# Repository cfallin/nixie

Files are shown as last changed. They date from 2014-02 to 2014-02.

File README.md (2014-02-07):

These are the raw Eagle schematic/PCB design files and the AVR firmware for a
Nixie tube clock.

Nixie tubes are gas-discharge neon display tubes. They take ~150 volts at a few
milliamps and glow a soft, pleasing orange. Each digit is a separate cathode in
a particular shape, so the numerals look more natural than more contemprary
7-segment display designs.

This project is a small microcontroller-based digital clock using 6 nixie tubes
(for HH:MM:SS). An ATmega16 8-bit AVR microcontroller keeps time based on its
20MHz system clock provided by a crystal oscillator, and controls six digit
driver ICs, one per Nixie tube. Each driver has high-voltage open-collector
outputs capable of directly interfacing with the display tube cathodes. The 150
volt anode supply is provided by a small switched-inductor boost converter,
which uses a power MOSFET driven by the microcontroller's PWM generator. The
design includes a feedback loop to an analog-to-digital (ADC) input on the AVR
so that it can regulate the tube voltage precisely.

Nixies can be found in various places online and often come from Russia. I
found mine on Etsy. Prices vary but I think the retro glow is well worth the
cost :-) The 74141 Nixie driver chips are also somewhat rare (e.g., not stocked
by Digikey) but can be found on eBay or at other small shops online.

=== DEVELOPMENT ENVIRONMENT ===

The firmware is written in C to be cross-compiled by avr-gcc. It assumes the
standard AVR headers that come with that compiler. The Makefile includes a
target to program the flash and fuses on the AVR using avrdude, but other
programmers can also be used.

The schematic and board were drawn in Eagle CAD. The additional libraries used
are included here.

=== IN PROGRESS ===

Work is currently in progress; in particular, the firmware is specific to an
earlier (hand-built) prototype version of the hardware and DOES NOT MATCH the
board. The board is currently (Feb 2014) out for a prototype run; when I build
the hardware designed here I'll update the firmware as appropriate.

=== LICENSE ===

All code, schematics and board design files here are Copyright (c) 2014 Chris
Fallin <cfallin@c1f.net>. Provided under the GNU GPL v2.

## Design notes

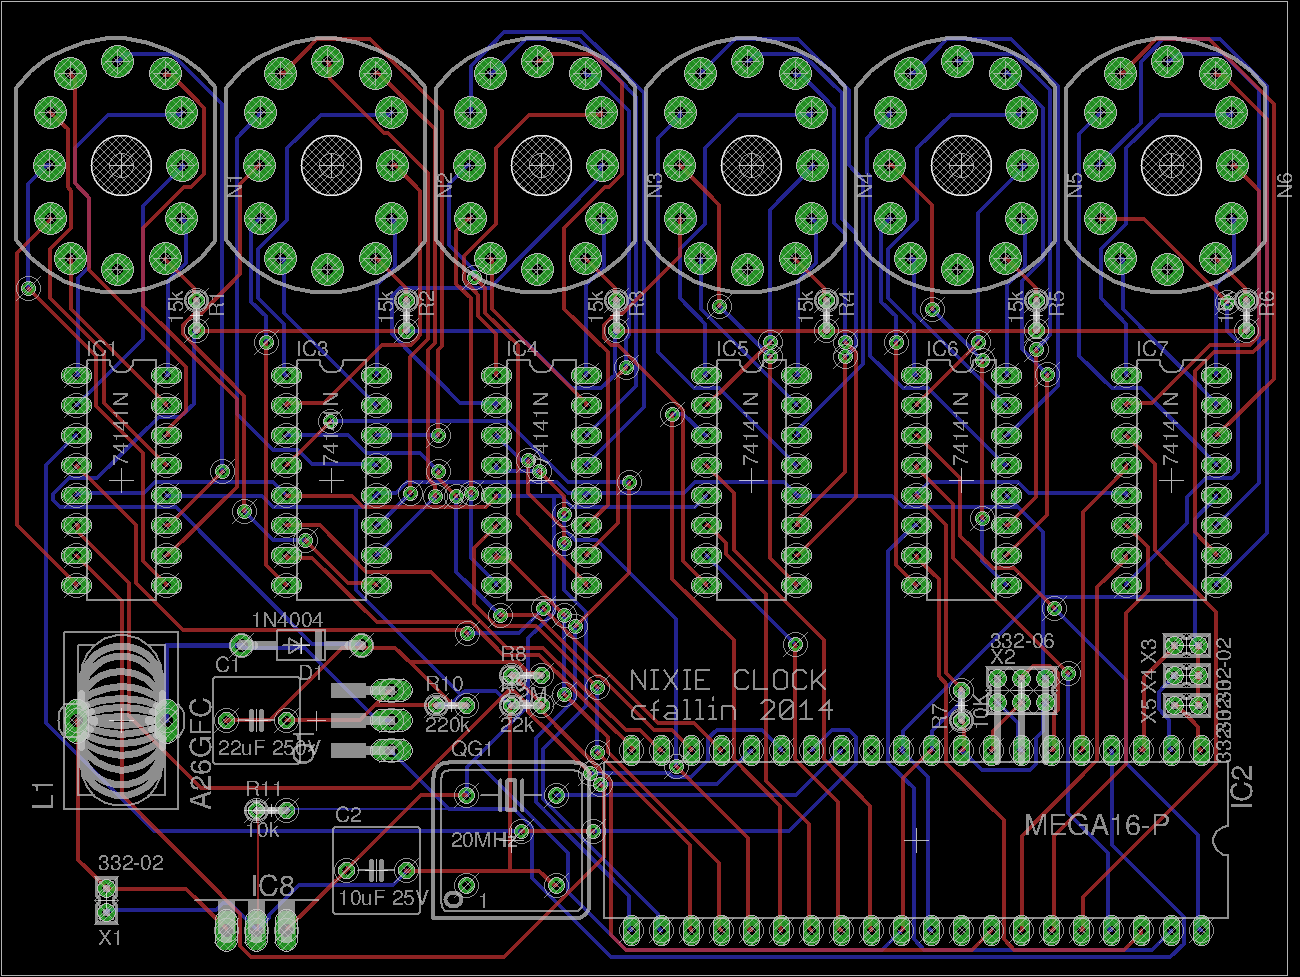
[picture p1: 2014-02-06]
board/nixie2.png

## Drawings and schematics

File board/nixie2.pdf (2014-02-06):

✁✂✁✂✄

☎✆

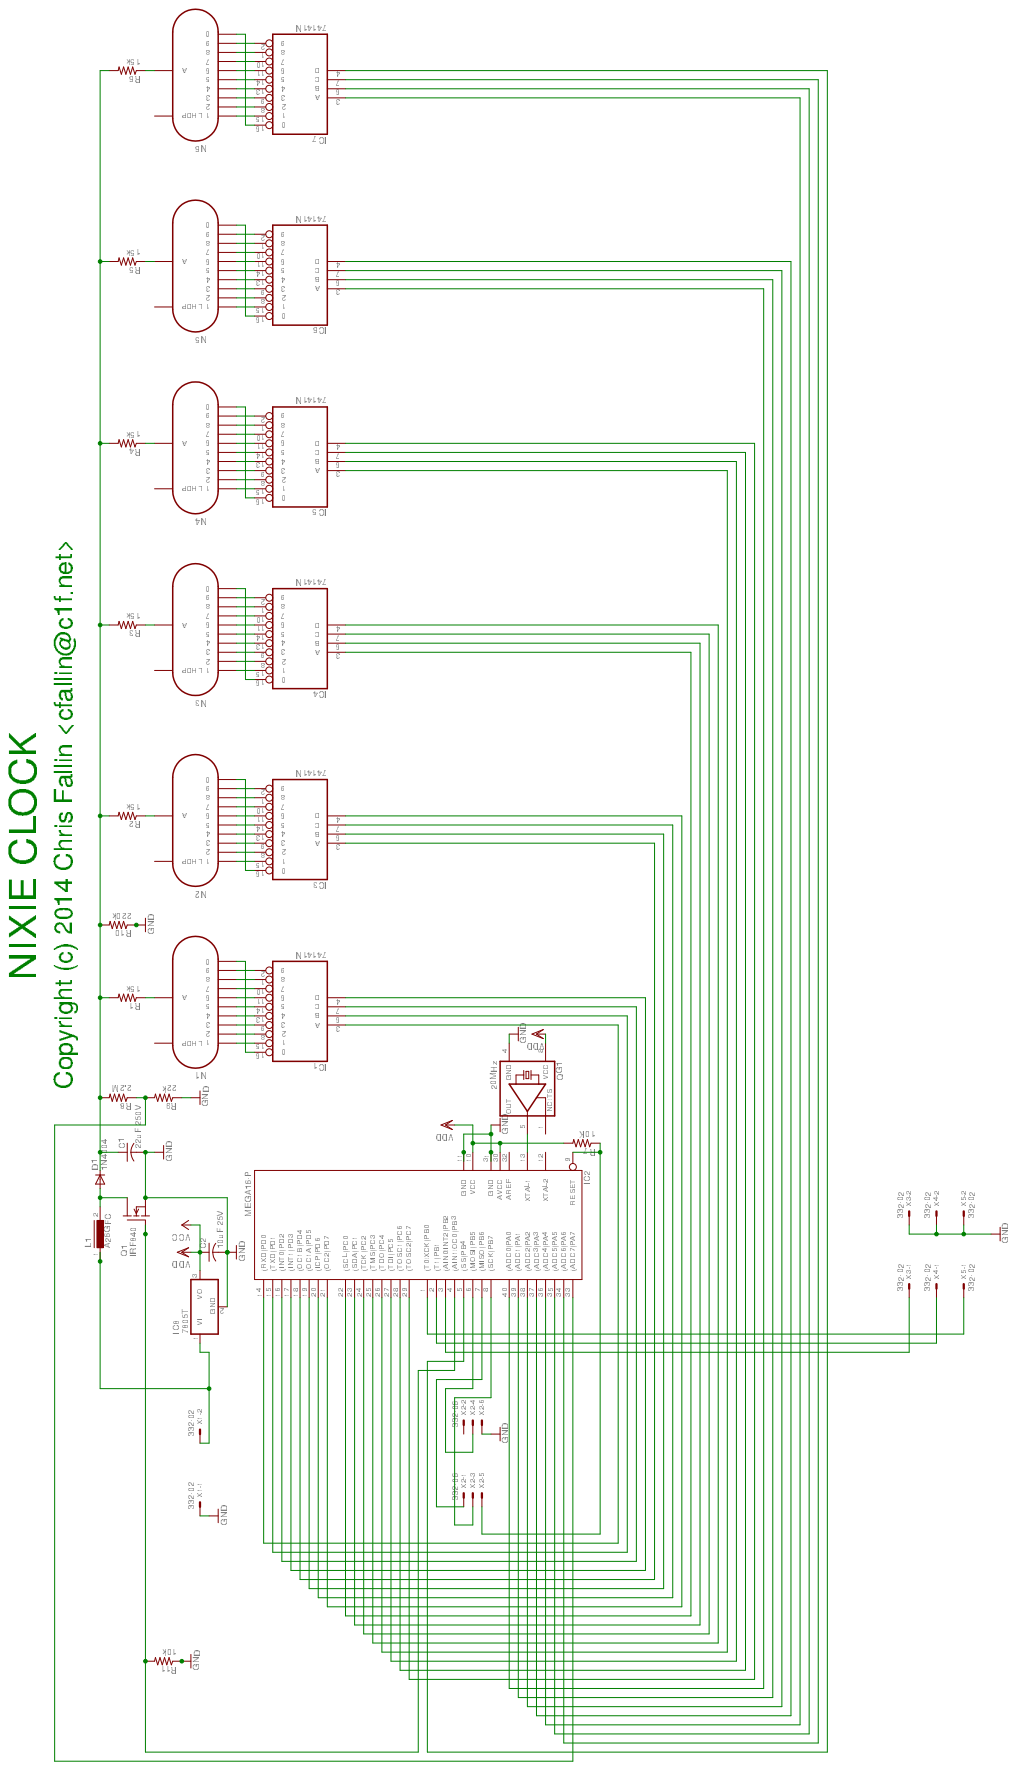
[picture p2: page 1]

✯✺
✯✯ | ✵
✯✵ | ✹
✯✳ | ✷

❦❧♠♥♦♣qrst✉✈✇①②③❦r♦♣④⑤⑥⑦⑦♣⑧⑨✉⑩⑥⑦⑦♣⑧❶✉②⑩❷⑧❸s❹

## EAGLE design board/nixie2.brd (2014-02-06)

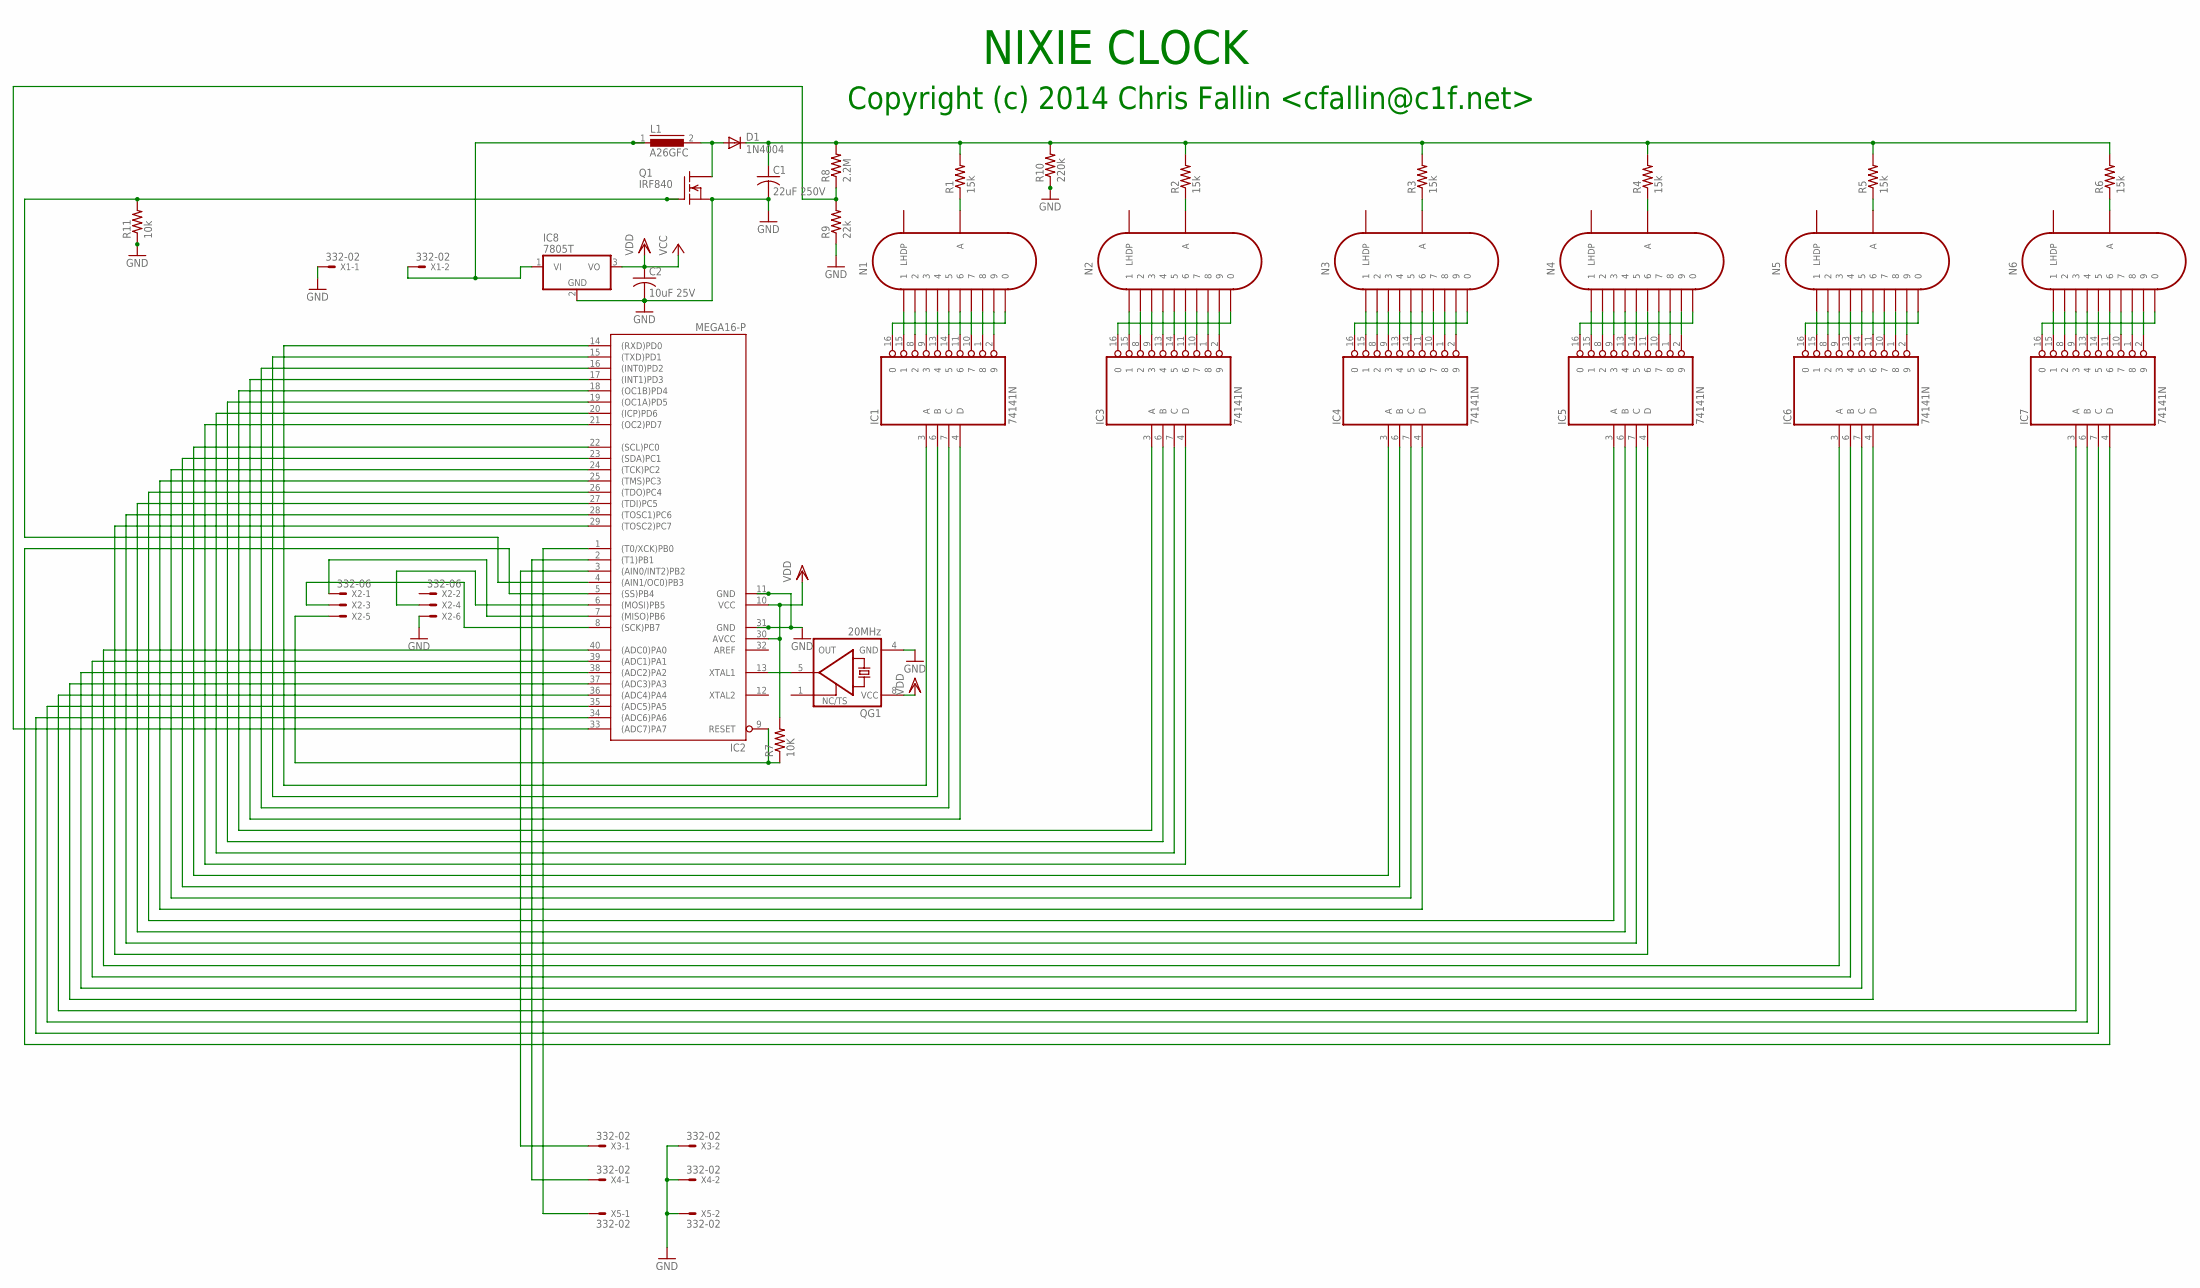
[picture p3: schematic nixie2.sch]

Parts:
C1: 22uF 250V; C050-075X075
C2: 10uF 25V; C050-075X075
D1: 1N4004; DO41-10
IC1, IC3, IC4, IC5, IC6, IC7: 74141N; DIL16
IC2: MEGA16-P; DIL40
IC8: 7805T; TO220H
L1: A26GFC
N1, N2, N3, N4, N5, N6: IN-12B; IN-12
Q1: IRF840; TO220
QG1: 20MHz; DIL08S
R1, R2, R3, R4, R5, R6: 15k; 0204V
R7: 10K; 0204V
R8: 2.2M; 0204V
R9: 22k; 0204V
R10: 220k; 0204V
R11: 10k; 0204V
X1, X3, X4, X5: 332-02
X2: 332-06

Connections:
GND: C1.2, C2.2, IC1.12 (GND), IC2.11 (GND), IC2.31 (GND), IC3.12 (GND), IC4.12 (GND), IC5.12 (GND), IC6.12 (GND), IC7.12 (GND), IC8.2 (GND), Q1.3 (S), QG1.4 (GND), R9.1, R10.1, R11.1, X1.1, X2.6, X3.2, X4.2, X5.2
unnamed: IC1.15 (1), N1.1
unnamed: IC1.8 (2), N1.2
unnamed: IC1.9 (3), N1.3
unnamed: IC1.13 (4), N1.4
unnamed: IC1.14 (5), N1.5
unnamed: IC1.11 (6), N1.6
unnamed: IC1.10 (7), N1.7
unnamed: IC1.1 (8), N1.8
unnamed: IC1.2 (9), N1.9
unnamed: N1.A, R1.1
unnamed: IC3.15 (1), N2.1
unnamed: IC3.8 (2), N2.2
unnamed: IC3.9 (3), N2.3
unnamed: IC3.13 (4), N2.4
unnamed: IC3.14 (5), N2.5
unnamed: IC3.11 (6), N2.6
unnamed: IC3.10 (7), N2.7
unnamed: IC3.1 (8), N2.8
unnamed: IC3.2 (9), N2.9
unnamed: IC3.16 (0), N2.0
unnamed: N2.A, R2.1
unnamed: IC4.15 (1), N3.1
unnamed: IC4.8 (2), N3.2
unnamed: IC4.9 (3), N3.3
unnamed: IC4.13 (4), N3.4
unnamed: IC4.14 (5), N3.5
unnamed: IC4.11 (6), N3.6
unnamed: IC4.10 (7), N3.7
unnamed: IC4.1 (8), N3.8
unnamed: IC4.2 (9), N3.9
unnamed: IC4.16 (0), N3.0
unnamed: N3.A, R3.1
unnamed: IC5.15 (1), N4.1
unnamed: IC5.8 (2), N4.2
unnamed: IC5.9 (3), N4.3
unnamed: IC5.13 (4), N4.4
unnamed: IC5.14 (5), N4.5
unnamed: IC5.11 (6), N4.6
unnamed: IC5.10 (7), N4.7
unnamed: IC5.1 (8), N4.8
unnamed: IC5.2 (9), N4.9
unnamed: IC5.16 (0), N4.0
unnamed: N4.A, R4.1
unnamed: IC6.15 (1), N5.1
unnamed: IC6.8 (2), N5.2
unnamed: IC6.9 (3), N5.3
unnamed: IC6.13 (4), N5.4
unnamed: IC6.14 (5), N5.5
unnamed: IC6.11 (6), N5.6
unnamed: IC6.10 (7), N5.7
unnamed: IC6.1 (8), N5.8
unnamed: IC6.2 (9), N5.9
unnamed: IC6.16 (0), N5.0
unnamed: N5.A, R5.1
unnamed: IC7.15 (1), N6.1
unnamed: IC7.8 (2), N6.2
unnamed: IC7.9 (3), N6.3
unnamed: IC7.13 (4), N6.4
unnamed: IC7.14 (5), N6.5
unnamed: IC7.11 (6), N6.6
unnamed: IC7.10 (7), N6.7
unnamed: IC7.1 (8), N6.8
unnamed: IC7.2 (9), N6.9
unnamed: IC7.16 (0), N6.0
unnamed: N6.A, R6.1
unnamed: C1.1, D1.C, R1.2, R2.2, R3.2, R4.2, R5.2, R6.2, R8.2, R10.2
unnamed: IC2.13 (XTAL1), QG1.5 (OUT)
unnamed: IC2.6 ((MOSI)PB5), X2.4
unnamed: D1.A, L1.2, Q1.2 (D)
unnamed: IC8.1 (VI), L1.1, X1.2
unnamed: IC2.7 ((MISO)PB6), X2.1
unnamed: IC2.8 ((SCK)PB7), X2.3
unnamed: IC2.9 (RESET), R7.1, X2.5
unnamed: IC1.3 (A), IC2.14 ((RXD)PD0)
unnamed: IC1.6 (B), IC2.15 ((TXD)PD1)
unnamed: IC1.7 (C), IC2.16 ((INT0)PD2)
unnamed: IC1.4 (D), IC2.17 ((INT1)PD3)
unnamed: IC2.18 ((OC1B)PD4), IC3.3 (A)
unnamed: IC2.19 ((OC1A)PD5), IC3.6 (B)
unnamed: IC2.20 ((ICP)PD6), IC3.7 (C)
unnamed: IC2.21 ((OC2)PD7), IC3.4 (D)
unnamed: IC2.22 ((SCL)PC0), IC4.3 (A)
unnamed: IC2.23 ((SDA)PC1), IC4.6 (B)
unnamed: IC2.24 ((TCK)PC2), IC4.7 (C)
unnamed: IC2.25 ((TMS)PC3), IC4.4 (D)
unnamed: IC2.26 ((TDO)PC4), IC5.3 (A)
unnamed: IC2.27 ((TDI)PC5), IC5.6 (B)
unnamed: IC2.28 ((TOSC1)PC6), IC5.7 (C)
unnamed: IC2.29 ((TOSC2)PC7), IC5.4 (D)
unnamed: IC2.4 ((AIN1/OC0)PB3), Q1.1 (G), R11.2
unnamed: IC2.40 ((ADC0)PA0), IC6.3 (A)
unnamed: IC2.39 ((ADC1)PA1), IC6.6 (B)
unnamed: IC2.38 ((ADC2)PA2), IC6.7 (C)
unnamed: IC2.37 ((ADC3)PA3), IC6.4 (D)
unnamed: IC2.36 ((ADC4)PA4), IC7.3 (A)
unnamed: IC2.35 ((ADC5)PA5), IC7.6 (B)
unnamed: IC2.34 ((ADC6)PA6), IC7.7 (C)
unnamed: IC2.5 ((SS)PB4), IC7.4 (D)
unnamed: IC2.33 ((ADC7)PA7), R8.1, R9.2
unnamed: IC2.3 ((AIN0/INT2)PB2), X3.1
unnamed: IC2.2 ((T1)PB1), X4.1
unnamed: IC2.1 ((T0/XCK)PB0), X5.1
unnamed: IC1.16 (0), N1.0
VDD: C2.1, IC1.5 (VCC), IC2.10 (VCC), IC2.30 (AVCC), IC3.5 (VCC), IC4.5 (VCC), IC5.5 (VCC), IC6.5 (VCC), IC7.5 (VCC), IC8.3 (VO), QG1.8 (VCC), R7.2

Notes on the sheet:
NIXIE CLOCK
Copyright (c) 2014 Chris Fallin <cfallin@c1f.net>

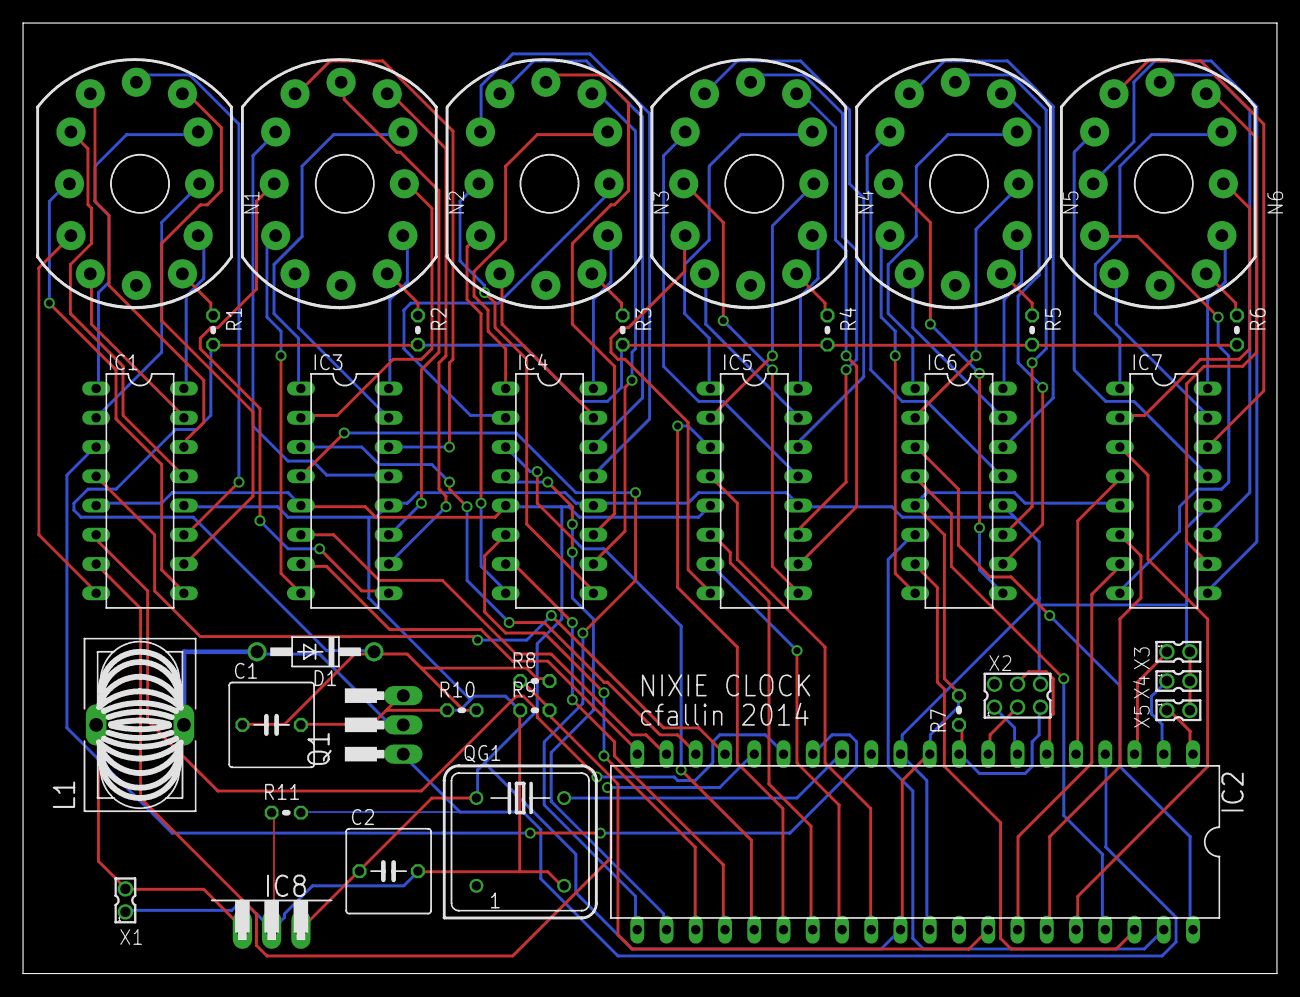
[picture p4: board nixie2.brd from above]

Board: 2 copper layers, 108.9 x 82.5 mm, 36 parts (0 on the bottom side), 105 nets.

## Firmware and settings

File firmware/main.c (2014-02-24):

/*
 * Nixie Clock
 *
 * Copyright (c) 2014 Chris Fallin <cfallin@c1f.net>
 * Placed under the GNU GPL v2.
 */

/* 
 * Assume an ATmega16.
 *
 * IO connections (manufactured board version):
 *
 * PD0..PD3 are BCD for H-tens digit.
 * PD4..PD7 are BCD for H-ones digit.
 * PC0..PC3 are BCD for M-tens digit.
 * PC4..PC7 are BCD for M-ones digit.
 * PA0..PA3 are BCD for S-tens digit.
 * PA4,PA5,PA6,PB4 are BCD for S-ones digit.
 *
 * PB3/OC0 is gate for power MOSFET on high-voltage boost converter.
 *
 * PA7 is analog feedback on high-voltage bus (1/101 resistive prescaler).
 *
 * PB0, PB1, PB2 are pushbuttons 1, 2, 3.
 */

#include <avr/io.h>
#include <avr/interrupt.h>

/* local functions */
static void init_time();
static void one_second();

static void init_display();
static void write_digit(char digit);
static void write_display();
static void init_buttons();
static void check_buttons();
static void init_smps();
static void adjust_smps();

typedef struct {
    unsigned char H, M, S;
    unsigned char ticks, correction;
} hms_time_t;

hms_time_t current_time;

unsigned char debounce_H, debounce_M, debounce_S;
unsigned char registered_H, registered_M, registered_S;

void init_time()
{
    current_time.H = current_time.M = current_time.S = 0;
    current_time.ticks = current_time.correction = 0;
    
    // set up timer 2
    TCNT2 = 0;
    TCCR2 = 0x47; // WGM mode 2 -- CTC (reset on match); clock source prescaler/1024
    OCR2 = 249;   // for a 20MHz clock, 20 / 1024 / 250 -> 78.125 Hz timer interrupt
    TIFR |= 0x80; // clear interrupt flag
    TIMSK |= 0x80; // enable timer 2 interrupt
    ASSR = 0; // disable asynchronous operation (external counts)
}

ISR(TIMER2_COMP_vect)
{
    adjust_smps();

    // increment 'ticks'; after 78.125 ticks, one second has elapsed.
    // We manage the fractional part by bumping the second display at
    // 78 ticks, but keeping a fractional part that's incremented
    // on each second. When the fractional part reaches 7, we wait an
    // extra tick to bump the second count.
    current_time.ticks++;

    if (current_time.ticks == 78) {

        one_second();

        current_time.ticks = 0;
        current_time.correction++;
        if (current_time.correction == 8) {
            current_time.correction = 0;
            current_time.ticks = 0xFF; // take an extra tick next second
        }
    }

    check_buttons();
}

void one_second()
{
    current_time.S++;
    if (current_time.S == 60) {
        current_time.S = 0;
        current_time.M++;
    }
    if (current_time.M == 60) {
        current_time.M = 0;
        current_time.H++;
    }
    if (current_time.H == 24) {
        current_time.H = 0;
    }

    write_display();
}

void init_display()
{
    // PD0..7, PC0..7, PA0..6, PB4 are outputs.
    // Start out with 0b1111 on all digits (digit blanked).
    PORTD = 0xff;
    DDRD = 0xff;
    PORTC = 0xff;
    DDRC = 0xff;
    PORTA |= 0x7f;
    DDRA |= 0x7f;
    PORTB |= 0x10;
    DDRB |= 0x10;
}

char lookup_ones[] = {
    0, 1, 2, 3, 4, 5, 6, 7, 8, 9,
    0, 1, 2, 3, 4, 5, 6, 7, 8, 9,
    0, 1, 2, 3, 4, 5, 6, 7, 8, 9,
    0, 1, 2, 3, 4, 5, 6, 7, 8, 9,
    0, 1, 2, 3, 4, 5, 6, 7, 8, 9,
    0, 1, 2, 3, 4, 5, 6, 7, 8, 9, };
char lookup_tens[] = {
    0, 0, 0, 0, 0, 0, 0, 0, 0, 0,
    1, 1, 1, 1, 1, 1, 1, 1, 1, 1,
    2, 2, 2, 2, 2, 2, 2, 2, 2, 2,
    3, 3, 3, 3, 3, 3, 3, 3, 3, 3,
    4, 4, 4, 4, 4, 4, 4, 4, 4, 4,
    5, 5, 5, 5, 5, 5, 5, 5, 5, 5, };

void write_display()
{
    // Hours and minutes are straight BCD out to the decoder/driver chips.
    // Note that ones digit of each is on high nibble rather than low nibble.
    PORTD = (lookup_tens[current_time.H]) | (lookup_ones[current_time.H] << 4);
    PORTC = (lookup_tens[current_time.M]) | (lookup_ones[current_time.M] << 4);

    // Seconds output has MSB on PB4 rather than PA7.
    uint8_t s = (lookup_tens[current_time.M]) | (lookup_ones[current_time.M] << 4);
    PORTA = (PORTA & 0x80) | (s & 0x7f);
    PORTB = (PORTB & 0xef) | ((s & 0x80) >> 3);
}

void init_buttons()
{
    DDRD &= ~0x07; // PD0, PD1, PD2 are inputs (H, M, S)

    debounce_H = debounce_M = debounce_S = 0;
    registered_H = registered_M = registered_S = 0;
}

void check_buttons()
{
    return;

    // check once per 78.125Hz tick. Three ticks with a '1' is sufficiently debounced
    // to register a button-press.
    
    if ((PINB & 0x01) && debounce_H < 3) // H button
        debounce_H++;
    else {
        debounce_H = 0;
        registered_H = 0;
    }
    if ((PINB & 0x02) && debounce_M < 3) // M button
        debounce_M++;
    else {
        debounce_M = 0;
        registered_M = 0;
    }
    if ((PINB & 0x04) && debounce_S < 3) // S-clear button
        debounce_S++;
    else {
        debounce_S = 0;
        registered_S = 0;
    }

    if (debounce_H == 3 && !registered_H) {
        current_time.H++;
        if (current_time.H == 24) current_time.H = 0;
        registered_H = 1;
    }
    if (debounce_M == 3 && !registered_M) {
        current_time.M++;
        if (current_time.M == 60) current_time.M = 0;
        registered_M = 1;
    }
    if (debounce_S == 3 && !registered_S) {
        current_time.S = 0;
        registered_S = 1;
    }
}

static void init_smps()
{
    //TCCR0 = (1<<WGM00) | (1<<WGM01) | (1<<COM01) | (1<<CS00);
    //OCR0 = 0x40;

    // set up OC0 (PB3) output, low by default until timer is set up
    PORTB &= ~8;
    DDRB |= 8;

    DDRA = 0xff;
    PORTA = 0;

    while (1) {
        PORTB |= 0x08;
        PORTB &= ~0x08;
        PORTA |= 1;
        PORTA &= ~1;
        asm volatile("nop; nop");
    }

    // set up ADC on voltage feedback pin
    ADMUX = 0xe0;  // 2.56V internal Vref, ADC0 (PC0) input, left-adjust result
    ADCSRA = 0xe7; // enable, start conversion, free-running, interrupts disabled, prescaler at clk/128

}

char __level = 0;

void adjust_smps()
{
    return;

    char val = ADCH;
    char target = 170; // 170 volts (voltage divider is 100:1; units of ADCH with 2.56V ref are 0.01V

    if (val > 190) { // safety shutoff at 190V
        OCR1A = 0;
    }
    if (val < target) {
        if (OCR1A < 0xa0) OCR1A++;
    }
    if (val > target) {
        if (OCR1A > 0) OCR1A--;
    }
}

int main()
{
    DDRB = 1;
    PORTB = 0;
    while(1) { PORTB ^= 1; }
    //init_time(); // initialize the time
    //init_display();
    //init_buttons();
    init_smps();
#if 1
    sei(); // enable interrupts
    while (1);

#else
    one_second();
    one_second();
    one_second();
    current_time.S = 9;

    while(1) write_display();
#endif
}

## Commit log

2014-02-06 Initial commit.
    [nixie2.brd, nixie2.sch]
2014-02-06 Image export of board.
2014-02-06 Schematic printout
    [nixie2.sch]
2014-02-06 Included additional libraries and PCB shop design rules.
2014-02-07 Moved all Eagle design files to board/.
    [nixie2.brd, nixie2.sch]
2014-02-24 Firmware update for ATmega16 and PCB pinout.
